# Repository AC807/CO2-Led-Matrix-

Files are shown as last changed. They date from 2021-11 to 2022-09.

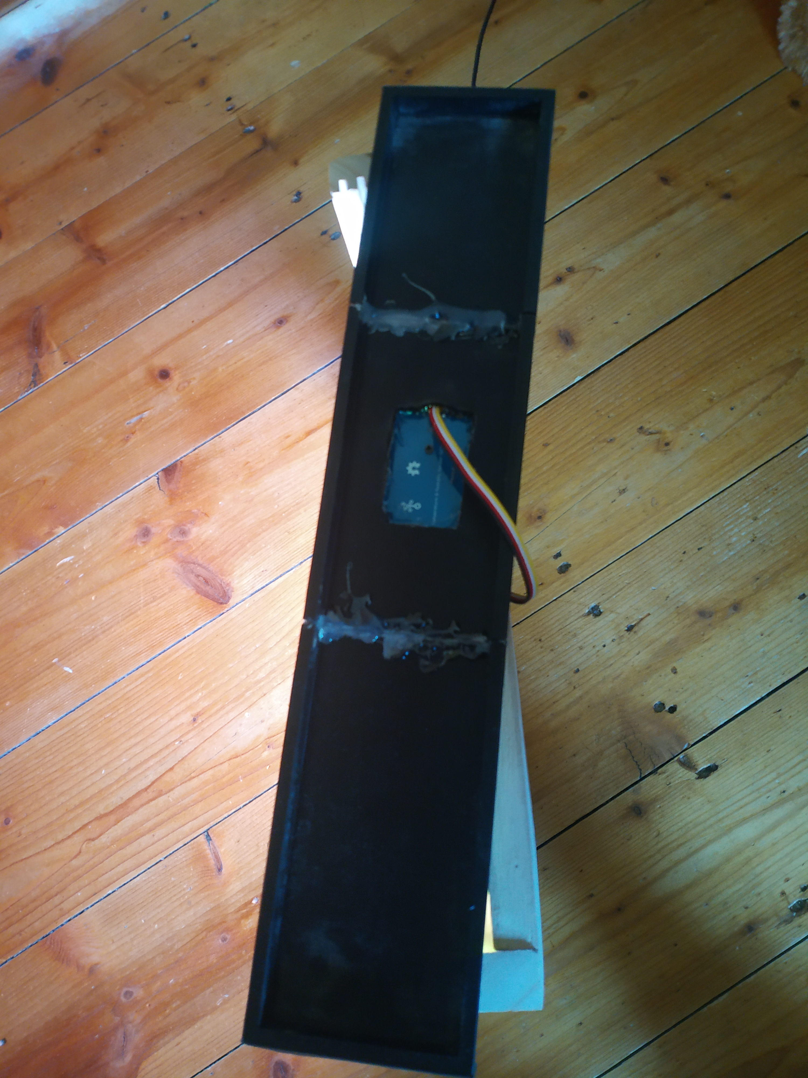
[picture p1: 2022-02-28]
Pres und bilder/IMG_20220207_152629.jpg

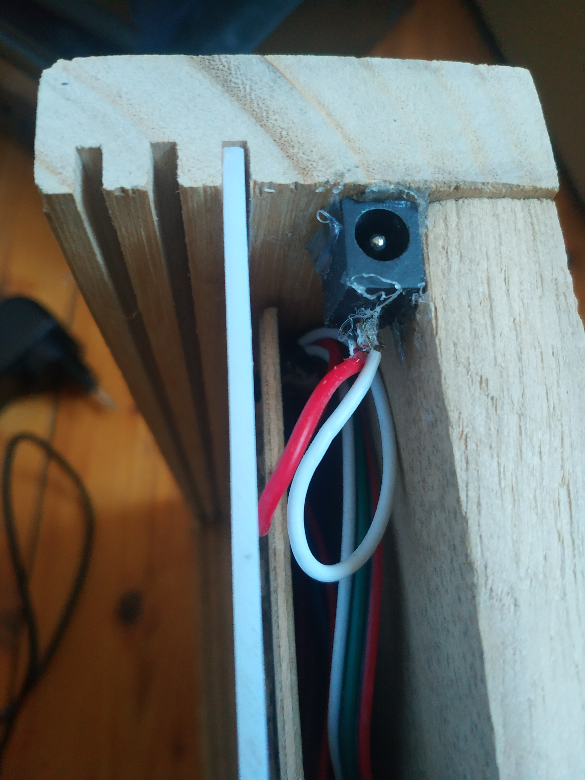
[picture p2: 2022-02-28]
Pres und bilder/IMG_20220207_162709.jpg

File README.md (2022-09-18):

# CO2-Led-Matrix-

Hallo,
das ist der Code zu meiner Jugend Forscht Arbeit mit dem Nahmen "Smarter CO2 Warner".
Hier die kurzfassung:

Ich habe mit einem Micro Computer (dem Octopus Board ESP-12F) und einem Co2 Sensor (dem SCD30) einen Co2 Warner für z.B. den Klassensaal gebaut. 
Der Co2 Wert wird auf einer 16x16 LED Matrix aus adressierbaren LED streifen angezeigt und zu einem Webserver geschickt. 
Unter 600ppm Co2 wird ein grüner Rahmen um die Zahl angezeigt, zwischen 600 und 1000pmm Co2 ein gelber Rahmen und über 1000ppm Co2 erscheint eine rote Warnmeldung. 
Außerdem habe ich ein Trend-Pfeil programmiert der anzeigt, ob der Co2 Wert konstant, fallend oder steigend ist. 
Für eine leichtere Handhabung des Warners habe ich aus Holz ein Gehäuse gebaut in welches man in 3 verschiedenen Höhen eine Milchglasscheibe einsetzen kann. 
Diese Scheibe ist dazu da, das Licht zu zerstreuen wodurch die Zahlen besser ablesbar werden.

Ich habe hierfür keine LED-Matrix libary genutzt.

Wenn jemand interresse am Code hat schreib mir einfach oder probiere ihn aus. (WIFI daten ändern)

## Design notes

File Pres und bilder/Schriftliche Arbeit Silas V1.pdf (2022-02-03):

# Smarter CO Warner ₂

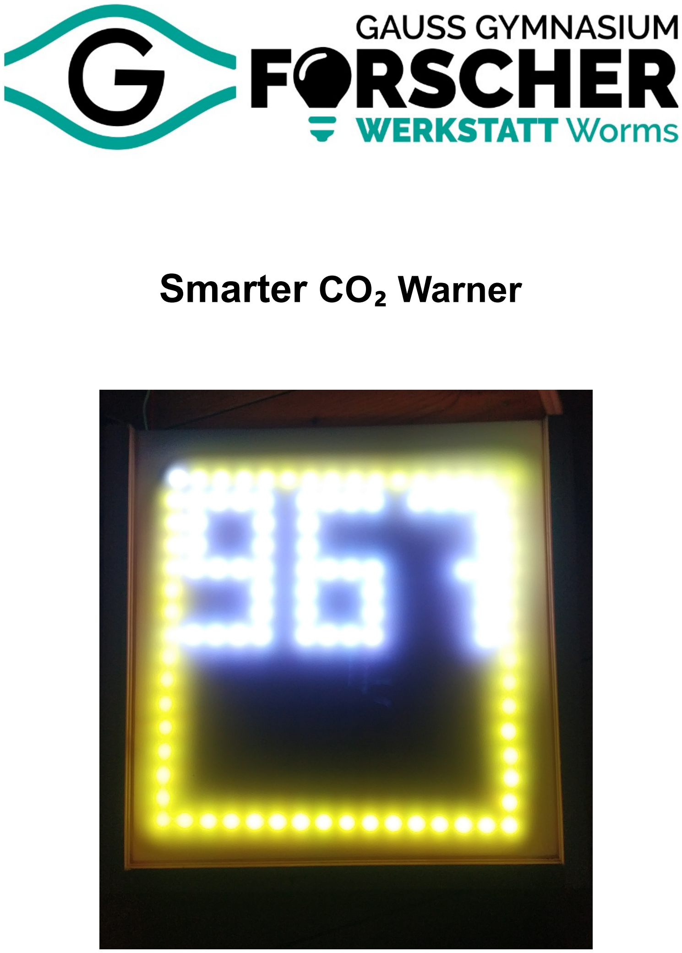
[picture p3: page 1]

## Diese Arbeit ist von Silas Wester 9D Gauß Gymnasium Worms

## Inhaltsverzeichnis

# Ziel

Mein Ziel ist es, einen praktischen CO Warner zu bauen der leicht abzulesen ist und ₂ nicht ablenkt. Hauptsächlich baue ich ihn für den Anwendungszweck in der Schule, da meine Schule noch keine CO Warner bekommen hat. ₂

## Warum ist ein CO Warner sinnvoll? ₂

Vom CO Gehalt in der Luft kann man Rückschlüsse auf die Raumluftqualität ₂ schließen da der CO Wert steigt, wenn sich mehrere Personen in einem Raum ₂ befinden und nicht gelüftet wird. Als Richtwert, wann man lüften sollte, habe ich 1000ppm gewählt, weil es z.B. vom Umweltbundesamt als Grenzwert angegeben wird.

## Ziel 1: Eine Basis die CO messen kann. ₂

Hier für habe ich ein Octopus Board und den SCD30 CO -, Temperatur- und ₂ Feuchtigkeitssensor verwendet. Ich habe eine Version des Sensors mit dem 12C BUS, weshalb ich nur 4 Leitungen brauche um den Sensor an mein Board anzuschließen.

Was ist ein Octopus Board?
Das Octopus Board basiert auf dem ESP-12F und ist ein Arduino-IDE kompatibles Entwicklerboard welches vom Umweltcampus der Hochschule Trier gebaut wird. Das Board ist interessant, da es z.B. einen WLAN Chip und einen 12C BUS Anschluss (für den CO Sensor) verbaut hat. ₂

Aufbau: Plug and code
Den CO Sensor musste ich nur an das Octopus Board anschließen und konnte ₂ direkt mit Programmieren beginnen.

Für den Code konnte ich große Teile des Beispiel Codes für den CO Sensor ₂ verwenden. Zum Visualisieren der Werte habe ich die auf dem Octopus board aufgelöteten NeoPixel LED verwendet. Bei einem CO Wehrt unter 600 ppm ₂ Leuchtet die LED grün, zwischen 600ppm und 1000ppm gelb und über 1000ppm rot. Außerdem gibt das Board den CO Wert auch über Serial.print an einen ₂ angeschlossenen PC aus.

## Ziel 2: Die CO Werte mit einem Webserver erreichbar ₂

machen.

Hierfür habe ich den Anbieter ThingSpeak benutzt, da er einfach zu benutzen ist und genau richtig für meinen Anwendungszweck. Auch hier habe ich wieder Teile des Beispiel Codes verwendet.
Jetzt misst der Sensor alle 2 sec. CO und das Octpus board schickt die Werte alle ₂ 10 sec. zu meinem ThingSpeak Server.
Bsp.:

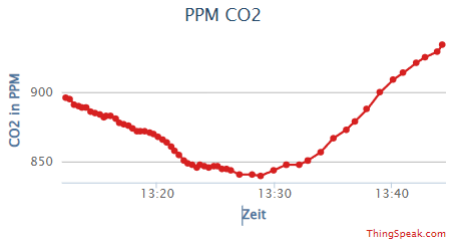
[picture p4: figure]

## Ziel 3: Eine intuitive Anzeige-Möglichkeit

Um den CO Wert anzuzeigen, habe ich eine LED Matrix mit 16x16 Pixeln aus ₂ WS28012b LEDs gebaut. Das hat den Vorteil, dass sie im Gegensatz zu einem normalen Display deutlich günstiger ist (insbesondere, wenn sie so groß ist, dass man sie in der Schule neben der Tafel hängend gut erkennen kann). Außerdem lenkt eine LED matrix auch nicht so ab wie ein Display.

Was ist eine LED Matrix?
Prinzipiell funktioniert eine LED Matrix ähnlich wie ein normales Display. In meinem Fall hat es aber nur eine Auflösung von 16x16 Pixeln. Ich habe hier 256 einzeln ansteuerbare LEDs verbaut, die ich dann so programmiert habe, dass man Zahlen anzeigen kann. Natürlich nur mit einer Auflösung von 16x16 Pixeln was aber für 3 Ziffern gut ausreicht.

Aufbau der Matrix:
Die Basis ist eine rechteckige Holzplatte auf die ich WS28012b LED-Streifen geklebt habe.
An die Stromkabel habe ich noch eine Buchse für ein 5V 4A Netzteil gelötet.
Nach 16 LEDs habe ich die Streifen abgeschnitten und in einer neuen Reihe angefangen.

Als nächstes musste ich die LED-Streifen mit Kabeln verbinden. Hierbei habe ich die Streifen so gelegt, dass die LEDs immer von links nach rechts angeordnet sind. Das hat den Vorteil, dass es leichter zu programmieren ist. Außerdem wird nur diese Anordnung von meinem gewählten Programm unterstützt.
Der Nachteil ist, dass ich die Kabel hinter der Matrix durchführen muss um wieder links am nächsten LED-Streifen anzukommen.
Damit ich die Matrix später in ein Gehäuse bauen kann und der Rand gleichmäßig ist, habe ich für die Kabel an jeder Seite der Reihen ein Loch gebohrt.

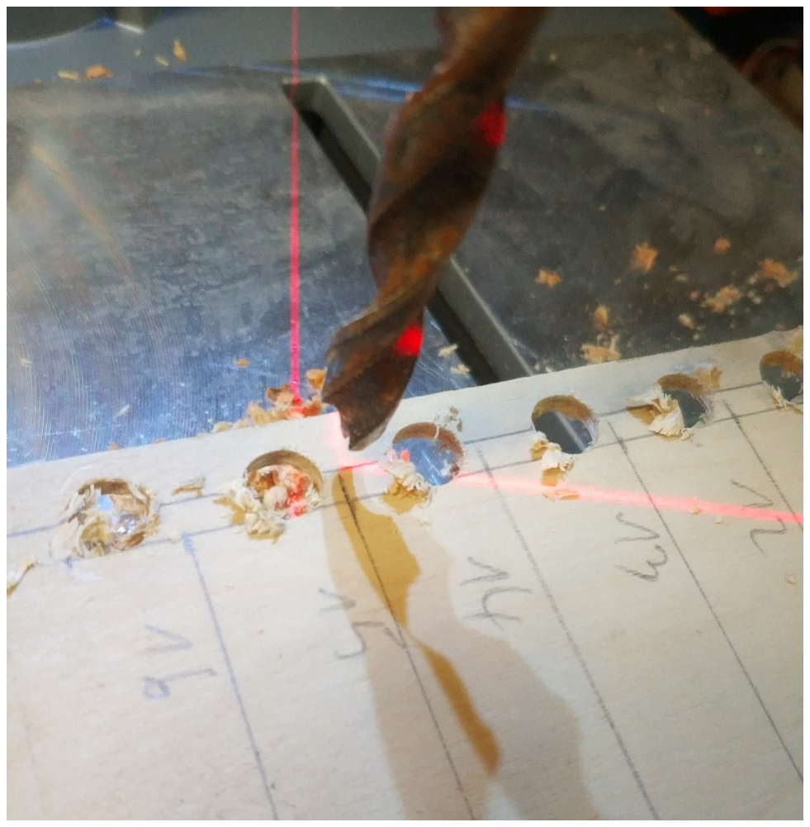
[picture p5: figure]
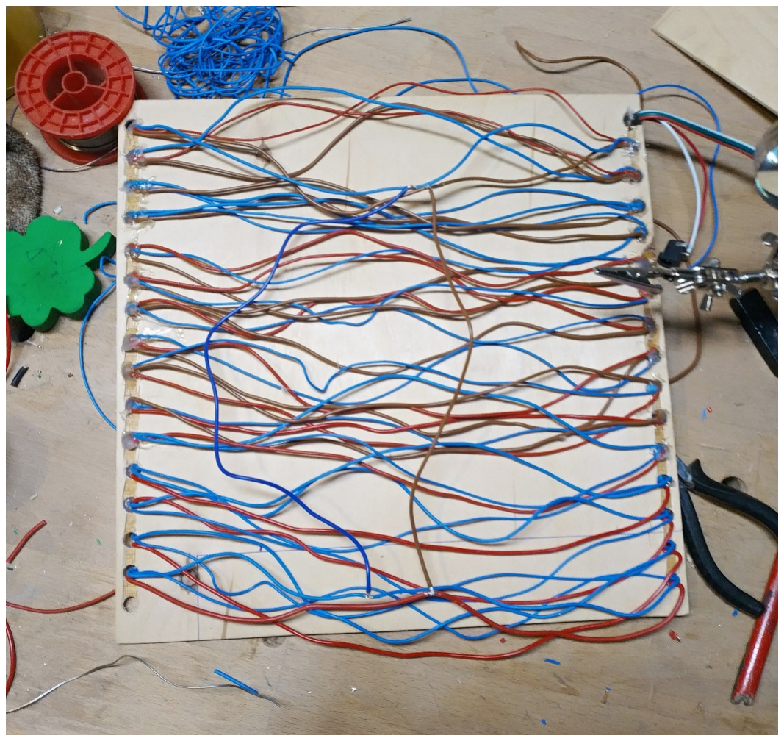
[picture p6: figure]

Beim Verlöten muss man aufpassen, dass man die Kabel vorher so biegt wie man sie braucht, da sie sich beim Löten mit Lötzinn vollsaugen und dann nicht mehr flexibel sind. Bei der 3. Reihe habe ich nämlich versucht die Kabel nach dem Löten noch einmal zu verbiegen und hab dabei das Lötpad von der Datenleitung abgerissen. Als Lösung habe ich dann das Kabel an die Unterseite des Streifens gelötet.
Beim ersten Test ist mir aufgefallen, dass wenn alle LEDs weiß leuchten sollen,die Farbe der letzten LEDs eher gelb ist. Dieser Effekt entsteht durch den Spannungsabfall. Das Problem habe ich behoben indem ich die letzten Stromleitungen mit den ersten verbunden habe.

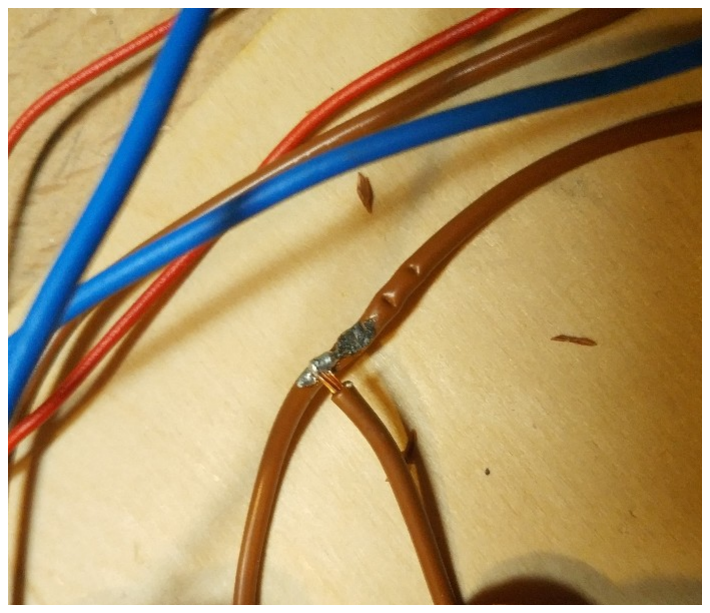
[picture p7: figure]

Was will ich auf der Matrix anzeigen?
- den CO Wert mit 3 Ziffern ₂
- einen Rahmen, der je nach CO Wert die Farbe wechselt (grün, gelb, rot) ₂
- eine große rote Meldung, wenn der CO Wert über 999ppm steigt ₂

Programmierung der LED-Matrix:
Um die LEDs einzeln anzusteuern, habe ich die FastLED library verwendet. Um 256 LEDs anzusteuern ist das aber sehr aufwendig, da ich für jede LED eine Zeile Code brauche um ihr zu sagen in welcher Farbe sie leuchten soll. Im Internet habe ich das Programm LEDMatrixControl von TylerTimoJ. In diesem Programm kann man auch unter anderem auf einer Fläche von 16x16 Pixeln zeichnen und sich die Bilder als Code für die FastLED library exportieren.
Dann habe ich die Zahlen von 0-9 für alle 3 Ziffern gezeichnet und exportiert.

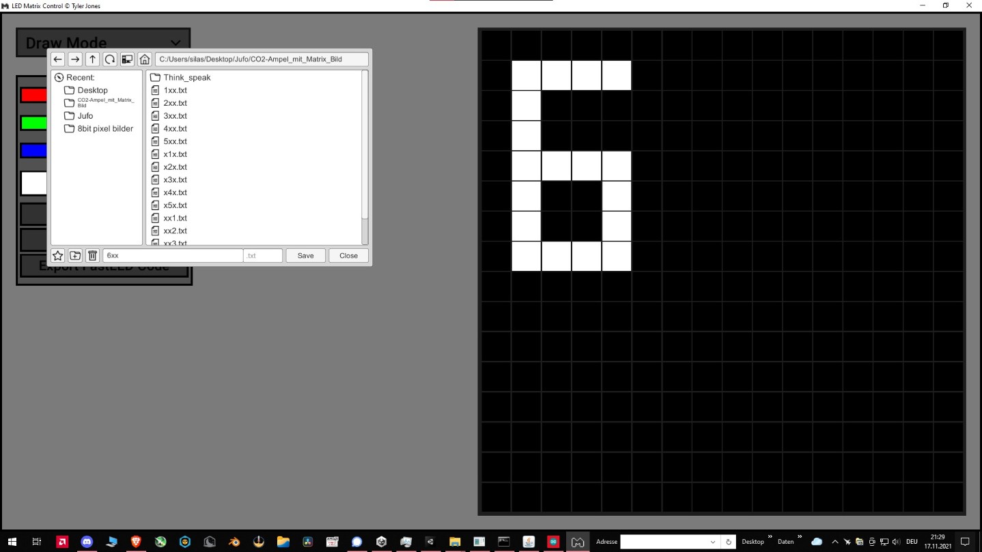
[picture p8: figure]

Als nächstes musste ich ein Programm entwickeln, welches den CO Wert bekommt ₂ und ausgibt welche LEDs wie leuchten müssen. Dafür muss es erst mal die Zahl in ihre Ziffern auftrennen da ich die Ziffern einzeln gezeichnet habe. Dafür habe ich mir zu Nutzen gemacht, dass bei einer Integer Variablen die Kommastellen wegfallen. Die Zahl wird durch 100 geteilt und ich erhalte die 100er Ziffer. Für die 10er Ziffer wird von der Zahl die 100er Ziffer mal 100 abgezogen und das ganze nochmal durch 10 geteilt. Für die 1er Ziffer wird auch die 100er Ziffer mal 100 abgezogen und dann das ganze durch die 10er Ziffer mal 10 subtrahiert.

Bsp.:
CO 378 ₂
100er Ziffer = 378/100 = 3
10er Ziffer = (378 - 3*100)/10 = 7
1er Ziffer = (378 – 3*100) – 7*10 = 8

Jetzt habe ich die Zahlen der einzelne Ziffern und kann z.B. sagen, dass wenn die 100er Ziffer 3 ist, führe den Code aus der auf der Matrix an der 100er stelle eine 3 anzeigt aus.

So sieht das in der Arduino IDE aus:

int CO = 0 ; //CO Wert ₂ | ₂
int w1xx = 0; //Zahl Ziffer 1
int wx1x = 0; //Zahl Ziffer 2
int wxx1 = 0; //Zahl Ziffer 3

void CO _Zerlegen (){ ₂
w1xx = CO /100; ₂
wx1x = (CO -w1xx*100)/10; ₂ wxx1 = (CO -w1xx*100)-wx1x*10; ₂ }

void loop() {
CO _Zerlegen (); ₂
if (w1xx == 1) v1xx();
if (w1xx == 2) v2xx();
if (w1xx == 3) v3xx();
if (w1xx == 4) v4xx();
...//abgekürzt ist zu lang
}

Als nächstes habe ich noch 3 Rahmen in grün, gelb und rot gezeichnet und integriert. Wenn der CO Wert unter 600ppm ist, wird der Code für den grünen Rahmen ₂ ausgeführt, zwischen 600ppm und 1000ppm der Code für den gelben Rahmen und über 1000ppm der Code für den roten Rahmen.

## Erster Testlauf

Im Dezember habe ich alle Komponenten miteinander verbunden und in meinem Zimmer platziert. Alles hat funktioniert wie geplant. Ich konnte den CO Wert sowohl ₂ auf der LED-Matrix als auch auf dem ThinkSpeak Webserver ablesen. Nach einiger Zeit ohne Lüftung wurde der Grenzwert erreicht und die Matrix leuchtete rot.

## Quellen

Warum ist ein CO Warner sinnvoll: ₂ | https://www.umweltbundesamt.de/richtig-lueften-
in-schulen#warum-ist-ein-regelmassiger-luftaustausch-in-klassenzimmerngrundsatzlich-wichtig-und-in-der-pandemie-umso-mehr (https://www.umweltbundesamt.de/richtig-lueften-in-schulen)
Octupus Board: https://www.bildung-forschung.digital/digitalezukunft/de/bildung/iot , https://www.umwelt-campus.de/iot-werkstatt/tutorials/schnellstart-octopusanschliessen-und-einrichten (https://www.umwelt-campus.de/iot-werkstatt/tutorials/schnellstart-octopus-anschliessen-und-einrichten)
CO Sensor: ₂ | https://www.distrelec.de/de/CO -temperatur-und-feuchtigkeitssensor- ₂
scd30-seeed-studio-101020634/p/30149396 (https://www.distrelec.de/de/co2-temperatur-und-feuchtigkeitssensor-scd30-seeed-studio-101020634/p/30149396)
Arduino IDE: https://www.arduino.cc/en/software
Fast LED : https://github.com/FastLED/FastLED
LEDMatrixControl: https://www.youtube.com/watch?v=YjzLWnPI_hg&t=1s

### Vielen Dank an Herr Kübler von der VSK-Technik Kübler für die

Unterstützung.

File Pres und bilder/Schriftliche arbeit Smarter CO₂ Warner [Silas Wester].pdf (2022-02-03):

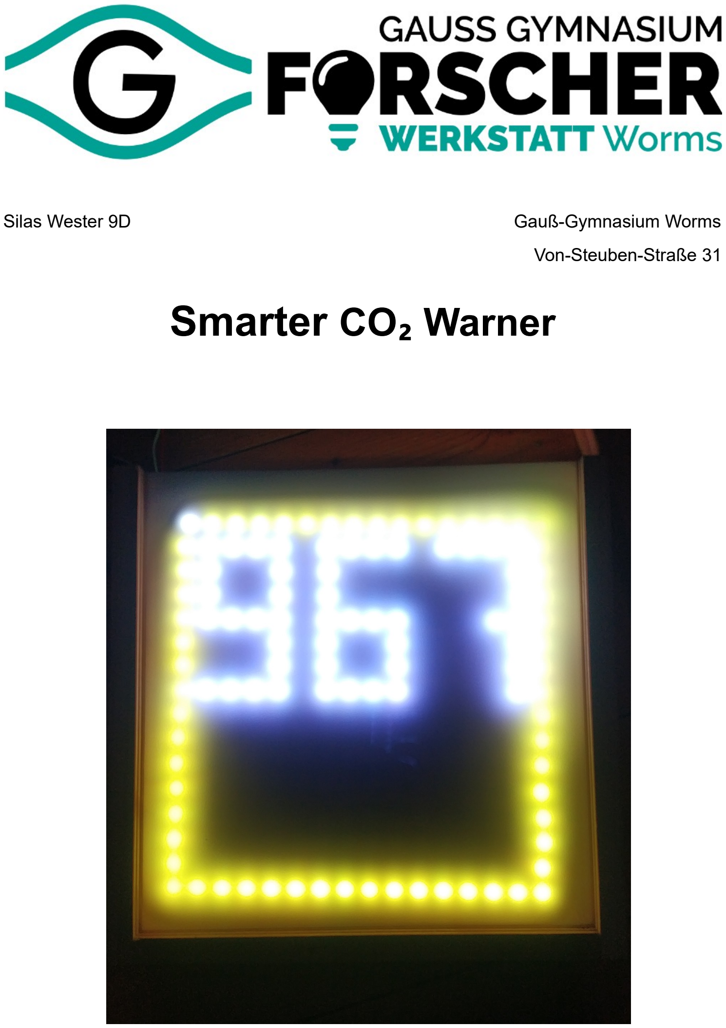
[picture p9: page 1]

Silas Wester 9D | Gauß-Gymnasium Worms
| Von-Steuben-Straße 31

# Smarter CO Warner ₂

## Inhaltsverzeichnis

# Ziel

Mein Ziel ist es, einen praktischen CO Warner zu bauen der leicht abzulesen ist und ₂ nicht ablenkt. Hauptsächlich baue ich ihn für den Anwendungszweck in der Schule, da meine Schule noch keine CO Warner bekommen hat und herkömmliche Modelle ₂ unpraktisch zum Ablesen sind oder keine genauen Werte liefern.

## Warum ist ein CO Warner sinnvoll? ₂

Vom CO Gehalt in der Luft kann man Rückschlüsse auf die Raumluftqualität ₂ schließen da der CO Wert steigt, wenn sich mehrere Personen in einem Raum ₂ befinden und nicht gelüftet wird. Als Richtwert, wann man lüften sollte, habe ich 1000 ppm gewählt, weil es z.B. vom Umweltbundesamt als Grenzwert angegeben wird.

## Ziel 1: Eine Basis die CO messen kann. ₂

Hier für habe ich ein Octopus Board und den SCD30 CO -, Temperatur- und ₂ Feuchtigkeitssensor verwendet. Ich habe eine Version des Sensors mit dem I²C BUS, weshalb ich nur 4 Leitungen brauche um den Sensor an mein Board anzuschließen.

Was ist ein Octopus Board?
Das Octopus Board basiert auf dem ESP-12F und ist ein Arduino-IDE kompatibles Entwicklerboard welches vom Umweltcampus der Hochschule Trier gebaut wird. Das Board ist interessant, da es z.B. einen WLAN Chip und einen I²C BUS Anschluss (für den CO Sensor) verbaut hat. ₂

Aufbau: Plug and code
Den CO Sensor musste ich nur an das ₂ Octopus Board anschließen und konnte direkt mit Programmieren beginnen.
Für den Code konnte ich große Teile des Beispiel Codes für den CO Sensor ₂

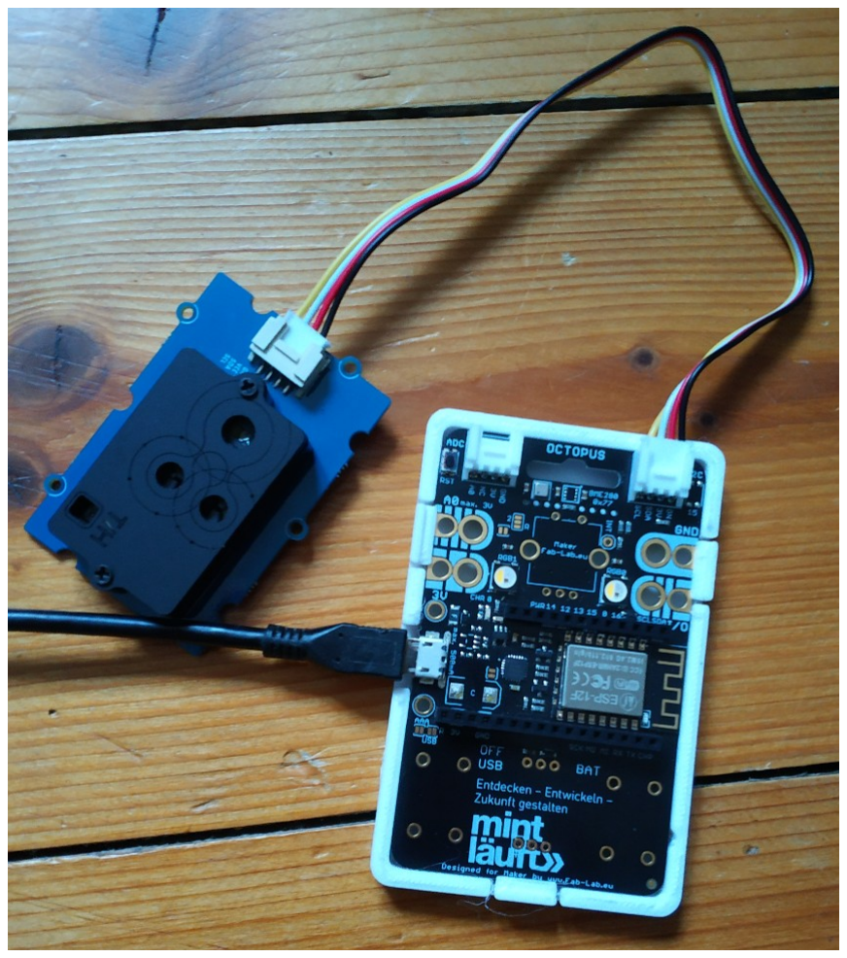
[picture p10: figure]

verwenden. Zum Visualisieren der Werte habe ich die auf dem Octopus board aufgelöteten NeoPixel LED verwendet. Bei einem CO₂ Wehrt unter 600 ppm Leuchtet die LED grün, zwischen 600 ppm und 1000 ppm gelb und über 1000 ppm rot.
Außerdem gibt das Board den CO Wert auch ₂ über Serial.print an einen angeschlossenen PC aus.

## Ziel 2: Die CO Werte mit einem Webserver erreichbar ₂

machen.

Hierfür habe ich den Anbieter ThingSpeak benutzt, da er einfach zu benutzen ist und genau richtig für meinen Anwendungszweck. Auch hier habe ich wieder Teile des Beispiel Codes verwendet.
Jetzt misst der Sensor alle 2 sec. CO und das Octpus board schickt die Werte alle ₂ 10 sec. zu meinem ThingSpeak Server.
Bsp.:

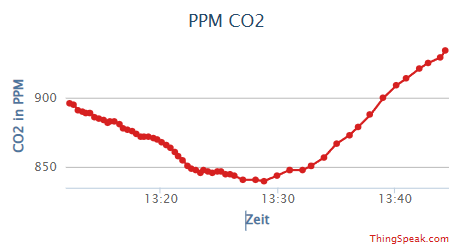
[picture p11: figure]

## Ziel 3: Eine intuitive Anzeige-Möglichkeit

Um den CO Wert anzuzeigen, habe ich eine LED Matrix mit 16x16 Pixeln aus ₂ WS28012b LEDs gebaut. Das hat den Vorteil, dass sie im Gegensatz zu einem normalen Display deutlich günstiger ist (insbesondere, wenn sie so groß ist, dass man sie in der Schule neben der Tafel hängend gut erkennen kann). Außerdem lenkt eine LED Matrix auch nicht so ab wie ein Display.

Was ist eine LED Matrix?
Prinzipiell funktioniert eine LED Matrix ähnlich wie ein normales Display. In meinem Fall hat es aber nur eine Auflösung von 16x16 Pixeln. Ich habe hier 256 einzeln ansteuerbare LEDs verbaut, die ich dann so programmiert habe, dass man Zahlen anzeigen kann. Natürlich nur mit einer Auflösung von 16x16 Pixeln was aber für 3 Ziffern gut ausreicht.

Aufbau der Matrix:
Die Basis ist eine rechteckige Holzplatte auf die ich WS28012b LED-Streifen geklebt habe.
An die Stromkabel habe ich noch eine Buchse für ein 5V 4A Netzteil gelötet.
Nach 16 LEDs habe ich die Streifen abgeschnitten und in einer neuen Reihe angefangen.

Als nächstes musste ich die LED-Streifen mit Kabeln verbinden. Hierbei habe ich die Streifen so gelegt, dass die LEDs immer von links nach rechts angeordnet sind. Das hat den Vorteil, dass es leichter zu programmieren ist. Außerdem wird nur diese Anordnung von meinem gewählten Programm unterstützt.
Der Nachteil ist, dass ich die Kabel hinter der Matrix durchführen muss um wieder links am nächsten LED-Streifen anzukommen.
Damit ich die Matrix später in ein Gehäuse bauen kann und der Rand gleichmäßig ist, habe ich für die Kabel an jeder Seite der Reihen ein Loch gebohrt.


Beim Verlöten muss man aufpassen, dass man die Kabel vorher so biegt wie man sie braucht, da sie sich beim Löten mit Lötzinn vollsaugen und dann nicht mehr flexibel sind. Bei der 3. Reihe habe ich nämlich versucht die Kabel nach dem Löten noch einmal zu verbiegen und hab dabei das Lötpad von der Datenleitung abgerissen. Als Lösung habe ich dann das Kabel an die Unterseite des Streifens gelötet.
Beim ersten Test ist mir aufgefallen, dass wenn alle LEDs weiß leuchten sollen,die Farbe der letzten LEDs eher gelb ist. Dieser Effekt entsteht durch den Spannungsabfall. Das Problem habe ich behoben indem ich die letzten Stromleitungen mit den ersten verbunden habe.


Was will ich auf der Matrix anzeigen?
- den CO Wert mit 3 Ziffern ₂
- einen Rahmen, der je nach CO Wert die Farbe wechselt (grün, gelb, rot) ₂
- eine große rote Meldung, wenn der CO Wert über 999 ppm steigt ₂

Programmierung der LED-Matrix:
Um die LEDs einzeln anzusteuern, habe ich die FastLED library verwendet. Um 256 LEDs anzusteuern ist das aber sehr aufwendig, da ich für jede LED eine Zeile Code brauche um ihr zu sagen in welcher Farbe sie leuchten soll. Im Internet habe ich das Programm LEDMatrixControl von TylerTimoJ. In diesem Programm kann man auch unter anderem auf einer Fläche von 16x16 Pixeln zeichnen und sich die Bilder als Code für die FastLED library exportieren.
Dann habe ich die Zahlen von 0-9 für alle 3 Ziffern gezeichnet und exportiert.


Als nächstes musste ich ein Programm entwickeln, welches den CO Wert bekommt ₂ und ausgibt welche LEDs wie leuchten müssen. Dafür muss es erst mal die Zahl in ihre Ziffern auftrennen da ich die Ziffern einzeln gezeichnet habe. Dafür habe ich mir zu Nutzen gemacht, dass bei einer Integer Variablen die Kommastellen wegfallen. Die Zahl wird durch 100 geteilt und ich erhalte die 100er Ziffer. Für die 10er Ziffer wird von der Zahl die 100er Ziffer mal 100 abgezogen und das ganze nochmal durch 10 geteilt. Für die 1er Ziffer wird auch die 100er Ziffer mal 100 abgezogen und dann das ganze durch die 10er Ziffer mal 10 subtrahiert.

Bsp.:
CO 378 ₂
100er Ziffer = 378/100 = 3
10er Ziffer = (378 - 3*100)/10 = 7
1er Ziffer = (378 – 3*100) – 7*10 = 8

Jetzt habe ich die Zahlen der einzelne Ziffern und kann z.B. sagen, dass wenn die 100er Ziffer 3 ist, führe den Code aus der auf der Matrix an der 100er stelle eine 3 anzeigt aus.

So sieht das in der Arduino IDE aus:

int CO = 0 ; //CO Wert ₂ | ₂
int w1xx = 0; //Zahl Ziffer 1
int wx1x = 0; //Zahl Ziffer 2
int wxx1 = 0; //Zahl Ziffer 3

void CO _Zerlegen (){ ₂
w1xx = CO /100; ₂
wx1x = (CO -w1xx*100)/10; ₂ wxx1 = (CO -w1xx*100)-wx1x*10; ₂ }

void loop() {
CO _Zerlegen (); ₂
if (w1xx == 1) v1xx();
if (w1xx == 2) v2xx();
if (w1xx == 3) v3xx();
if (w1xx == 4) v4xx();
...//abgekürzt ist zu lang
}

Als nächstes habe ich noch 3 Rahmen in grün, gelb und rot gezeichnet und integriert. Wenn der CO Wert unter 600 ppm ist, wird der Code für den grünen Rahmen ₂ ausgeführt, zwischen 600 ppm und 1000 ppm der Code für den gelben Rahmen und über 1000 ppm der Code für den roten Rahmen.

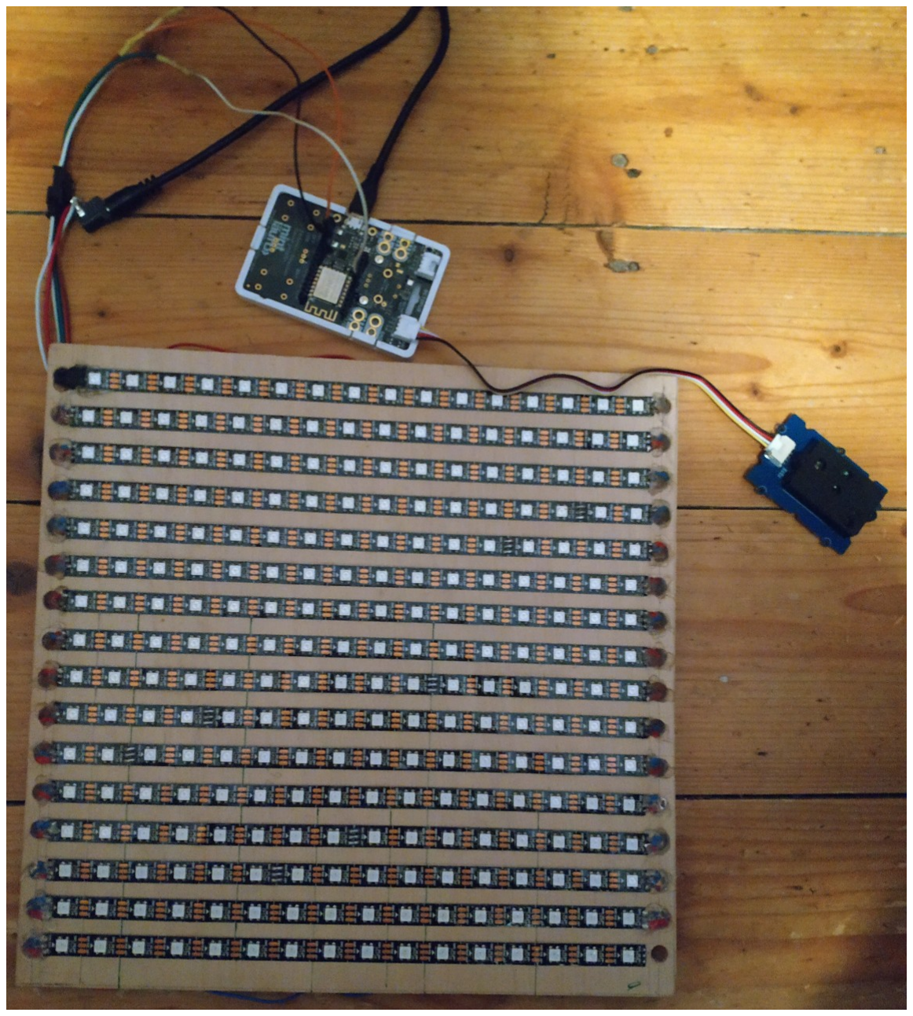
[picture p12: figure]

## Erster Testlauf und Ergebnis

Im Dezember habe ich alle Komponenten miteinander verbunden und in meinem Zimmer platziert. Alles hat funktioniert wie geplant. Ich konnte den CO Wert sowohl ₂ auf der LED-Matrix als auch auf dem ThinkSpeak Webserver ablesen. Nach einiger Zeit ohne Lüftung wurde der Grenzwert erreicht und die Matrix leuchtete rot. Dadurch wurden die Ziele erreicht. Das Gerät kann in der Schule eingesetzt werden um die Gesundheit der Schüler und Lehrer zu schützen. Außerdem kann durch die Verbesserung der Luftqualität die Konzentration und das Wohlbefinden gesteigert werden.

## Ausblick

Auf jeden Fall ist noch ein Gehäuse geplant, womit ich auch schon angefangen habe aber noch Teile 3d-drucken muss.
Einen eigenen Server als Alternative für ThinkSpeak wäre auch noch eine Überlegung.
Außerdem könnte man die CO Wert auch in die Schul-raumplanung einfließen ₂ lassen. Wenn eine Klasse z.B. kurzfristig in einen anderen Raum muss kann man den Raum danach auswählen wie viel CO in der Luft ist. ₂

## Quellen

Warum ist ein CO Warner sinnvoll: ₂ | https://www.umweltbundesamt.de/richtig-lueften-
in-schulen#warum-ist-ein-regelmassiger-luftaustausch-in-klassenzimmerngrundsatzlich-wichtig-und-in-der-pandemie-umso-mehr (https://www.umweltbundesamt.de/richtig-lueften-in-schulen)
Octupus Board: https://www.bildung-forschung.digital/digitalezukunft/de/bildung/iot , https://www.umwelt-campus.de/iot-werkstatt/tutorials/schnellstart-octopusanschliessen-und-einrichten (https://www.umwelt-campus.de/iot-werkstatt/tutorials/schnellstart-octopus-anschliessen-und-einrichten)
CO Sensor: ₂ | https://www.distrelec.de/de/CO -temperatur-und-feuchtigkeitssensor- ₂
scd30-seeed-studio-101020634/p/30149396 (https://www.distrelec.de/de/co2-temperatur-und-feuchtigkeitssensor-scd30-seeed-studio-101020634/p/30149396)
Arduino IDE: https://www.arduino.cc/en/software
Fast LED : https://github.com/FastLED/FastLED
LEDMatrixControl: https://www.youtube.com/watch?v=YjzLWnPI_hg&t=1s

### Vielen Dank an Herr Kübler von der VSK-Technik Kübler für die

Unterstützung.

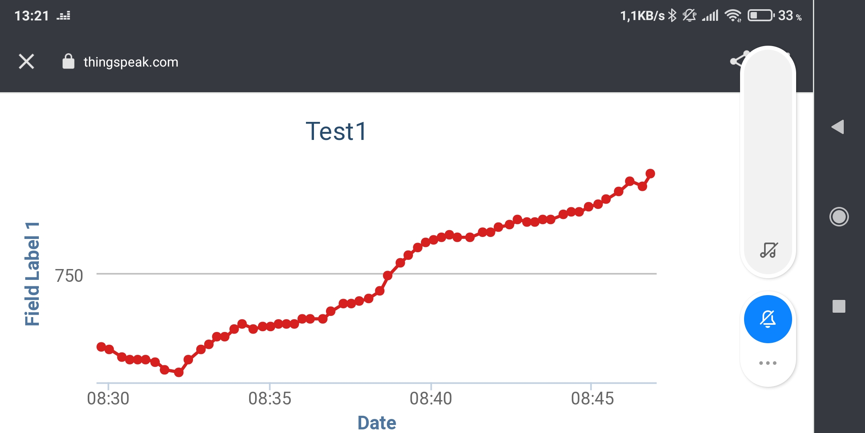
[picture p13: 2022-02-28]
Pres und bilder/Screenshot_2022-02-09-13-21-27-925_com.android.chrome.jpg

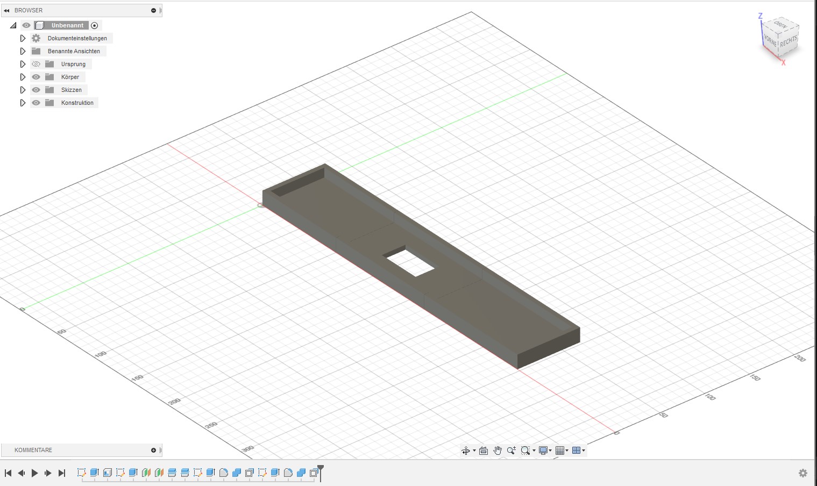
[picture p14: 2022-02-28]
Pres und bilder/Screenshot 2022-02-07 153404.jpg

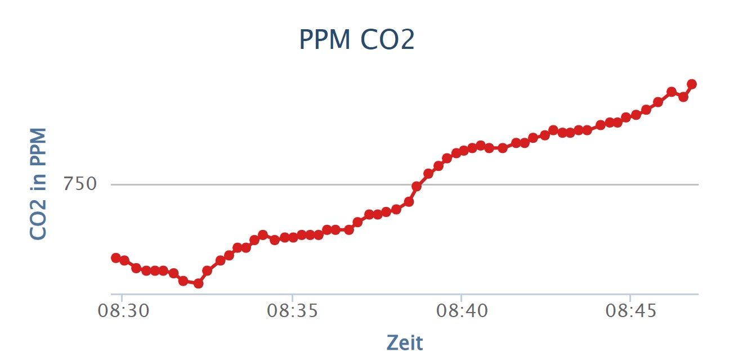
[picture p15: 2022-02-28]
Pres und bilder/Screenshot 2022-02-09 181810.jpg

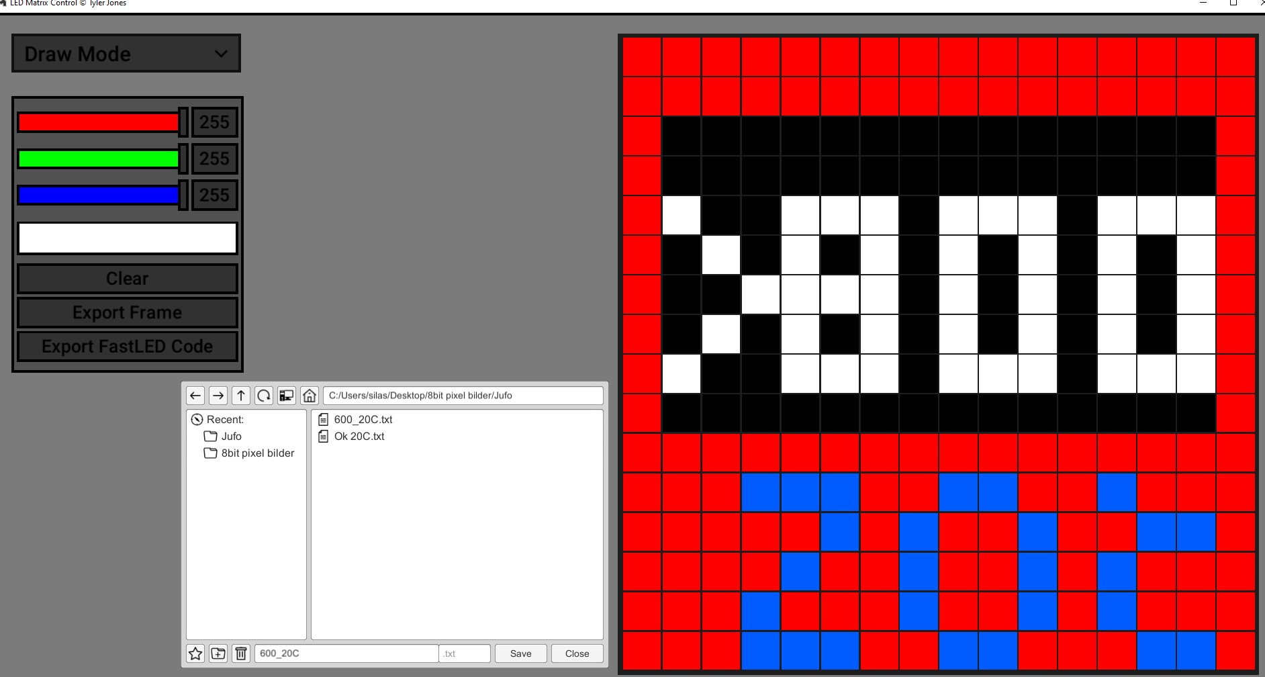
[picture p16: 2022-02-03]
Pres und bilder/Screenshot 2021-10-14 112025.jpg

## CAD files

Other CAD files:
JuFo_CO2_Matrix_Kappe_v1_v6.f3d

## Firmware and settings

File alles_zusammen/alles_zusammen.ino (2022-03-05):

#include "FastLED.h"
#define NUM_LEDS 256 //anzahl der LEDs (16x16)
#include <ESP8266WiFi.h>
#include <SparkFun_SCD30_Arduino_Library.h>
#include <Wire.h>
#include <Adafruit_NeoPixel.h>
CRGB leds[NUM_LEDS];
int CO2 = 0 ; //Co2-Wert
int alt_CO2 = 0; //alter Co2-Wert
int w1xx = 0;   //100er Stelle
int wx1x = 0;   //10er Stelle
int wxx1 = 0;   //1er Stelle
int CO2diff = -1; //CO2 Differenz (CO2-alt_CO2)

SCD30 airSensorSCD30; // Objekt SDC30 Umweltsensor
IPAddress myOwnIP; // ownIP for mDNS 

//--------------------------------------- HTTP-Get
int httpGET(String host, String cmd, String &antwort,int Port) {
  WiFiClient client; // Client über WiFi
  String text = "GET http://"+ host + cmd + " HTTP/1.1\r\n";
  text = text + "Host:" + host + "\r\n";
  text = text + "Connection:close\r\n\r\n";
  int ok = 1;
  if (ok) { // Netzwerkzugang vorhanden 
    ok = client.connect(host.c_str(),Port);// verbinde mit Client
    if (ok) {
      client.print(text);                 // sende an Client 
      for (int tout=1000;tout>0 && client.available()==0; tout--)
        delay(10);                         // und warte auf Antwort
      if (client.available() > 0)         // Anwort gesehen 
        while (client.available())         // und ausgewertet
          antwort = antwort + client.readStringUntil('\r');
      else ok = 0;
      client.stop(); 
      Serial.println(antwort);
    } 
  } 
  if (!ok) Serial.print(" no connection"); // Fehlermeldung
  return ok;
}

void setup(){ // Einmalige Initialisierung
  Wire.begin(); // ---- Initialisiere den I2C-Bus 
 
  Serial.begin(115200);  
  Serial.println();
  Wire.setClock(100000L);            // 100 kHz SCD30 
  Wire.setClockStretchLimit(200000L);// CO2-SCD30
  
  if (Wire.status() != I2C_OK) Serial.println("Fehler auf dem I2C-Bus");

  if (airSensorSCD30.begin() == false) {
    Serial.println("SCD30-Sensor Verbindung fehlerhaft, bitte prüfen"); 
  }

  airSensorSCD30.setAutoSelfCalibration(false); // Sensirion no auto calibration

  airSensorSCD30.setMeasurementInterval(2);     // CO2-Messung alle 2 s




  
  //------------ WLAN initialisieren 
  WiFi.persistent(false);
  WiFi.mode(WIFI_STA);
  delay(100);
  Serial.print ("\nWLAN connect to:");
  Serial.print("Gastzugang");
  WiFi.begin("Gastzugang","31155182573812659566");
  while (WiFi.status() != WL_CONNECTED) { // Warte bis Verbindung steht 
    delay(500); 
    Serial.print(".");    //Lade Punkte ausgeben
  };
  Serial.println ("\nconnected, meine IP:"+ WiFi.localIP().toString()); //IP addresse ausgeben
  myOwnIP = WiFi.localIP();
  
FastLED.addLeds<NEOPIXEL,13>(leds, NUM_LEDS); //LEDs hinzufügen
}

void loop() { // Kontinuierliche Wiederholung 
  CO2 = airSensorSCD30.getCO2() ;  //CO2 Wert in CO2 schriben
  Serial.print("CO2:"+String(String(CO2))); //CO2 ausgeben
  Serial.println();     //lehrzeile 

  { //Block------------------------------ sende Daten an Thingspeak (mit http GET) 
    Serial.println("\nThingspeak update ");
    String cmd = "/update?api_key="+ String("X3EXNK3ZO6R3IVI2");
    String host = "api.thingspeak.com";
    String antwort= " ";
    cmd = cmd +String("&field1="+String(CO2))+ "\n\r";
    httpGET(host,cmd,antwort,80);// und absenden 
  } // Blockende
 
CO2_Zerlegen ();    //schleife um CO2 in Ziffern zu zerlegen
empty();      //alle LEDs aus
//Zahl anzeigen:
if (w1xx == 1) v1xx();
if (w1xx == 2) v2xx();
if (w1xx == 3) v3xx();
if (w1xx == 4) v4xx();
if (w1xx == 5) v5xx();
if (w1xx == 6) v6xx();
if (w1xx == 7) v7xx();
if (w1xx == 8) v8xx();
if (w1xx == 9) v9xx();
if (w1xx == 0) v0xx();

if (wx1x == 1) vx1x();
if (wx1x == 2) vx2x();
if (wx1x == 3) vx3x();
if (wx1x == 4) vx4x();
if (wx1x == 5) vx5x();
if (wx1x == 6) vx6x();
if (wx1x == 7) vx7x();
if (wx1x == 8) vx8x();
if (wx1x == 9) vx9x();
if (wx1x == 0) vx0x();

if (wxx1 == 1) vxx1();
if (wxx1 == 2) vxx2();
if (wxx1 == 3) vxx3();
if (wxx1 == 4) vxx4();
if (wxx1 == 5) vxx5();
if (wxx1 == 6) vxx6();
if (wxx1 == 7) vxx7();
if (wxx1 == 8) vxx8();
if (wxx1 == 9) vxx9();
if (wxx1 == 0) vxx0();

Pfeil(); //Schleife um Trend-Pfeil anzuzeigen
farbeermitteln();   //Schleife um Farbigen Rahmen anzuzeigen
FastLED.show();     //Daten zur Matrix schicken 
Serial.println("CO2 1xx:"+String(String(w1xx)));
Serial.println("CO2 x1x:"+String(String(wx1x)));
Serial.println("CO2 xx1:"+String(String(wxx1)));
Serial.println("CO2 -alt_CO2:"+String(String(CO2diff)));
Serial.println("alt_CO2 :"+String(String(alt_CO2)));
alt_CO2 = CO2;   // CO2 in alt_CO2 speichern 
delay( 2000 );    //2 sec Warten bis neuer durchlauf
Serial.println("neuer durchlauf");
}

void CO2_Zerlegen (){
w1xx = CO2/100;
wx1x = (CO2-w1xx*100)/10;
wxx1 = (CO2-w1xx*100)-wx1x*10;
}

void Pfeil() {
CO2diff = CO2 - alt_CO2;   //CO2 Differenz berechnen
  if (( ( CO2diff ) > ( 8 ) ))    //ist die CO2diff größer als 8?
  {
    pf_steigend();
    Serial.println("steigender CO2 Wert");
    }
   else
     if (( ( CO2diff ) > ( 3 ) && ( CO2diff )< ( 9 ) ))     //ist die CO2diff zwichen als 4 und 8?
  {
    pf_leicht_steigend();
    Serial.println("leicht steigender CO2 Wert");
    }
   else
     if (( ( CO2diff ) < ( 4 ) && ( CO2diff )> ( -4 ) ))     //ist die CO2diff zwichen als 3 und -3?   
  {
    pf_gleich();
    Serial.println("Konstanter CO2 Wert");
    }
  else
     if (( ( CO2diff ) < ( -3 ) && ( CO2diff )> ( -9 ) ))     //ist die CO2diff zwichen als -4 und -8?
  {
  pf_leicht_sinkend();
  Serial.println("leicht sinkender CO2 Wert");
  }
  else
  if (( ( CO2diff ) < ( -8 ) ))     //ist die CO2diff kleiner als -8?
  {
  pf_sinkend();
  Serial.println("sinkender CO2 Wert");
    }
  }

void farbeermitteln()
{
  if (( ( CO2 ) < ( 600 ) ))     //ist CO2 kleiner als 600?
  {
    Serial.print("green");
    Serial.println();
    vGruen_Rahmen ();

  }
  else    //wenn nicht
  {
    if (( ( CO2 ) < ( 1000 ) ))     //ist CO2 kleiner als 1000?
    {
      Serial.print("yellow");
      Serial.println();
      vGelb_Rahmen ();
    }
    else    //wenn nicht
    {
      Serial.print("red");
      Serial.println();
     to_high ();
    }
  }
}


                                //alle Schleifen um etwas anzuzeigen
void vxx1(){
leds[29] = CRGB(255, 255, 255);
leds[30] = CRGB(255, 255, 255);
leds[44] = CRGB(255, 255, 255);
leds[46] = CRGB(255, 255, 255);
leds[59] = CRGB(255, 255, 255);
leds[62] = CRGB(255, 255, 255);
leds[78] = CRGB(255, 255, 255);
leds[94] = CRGB(255, 255, 255);
leds[110] = CRGB(255, 255, 255);
leds[126] = CRGB(255, 255, 255);
  }
void vxx2(){
leds[28] = CRGB(255, 255, 255);
leds[29] = CRGB(255, 255, 255);
leds[43] = CRGB(255, 255, 255);
leds[46] = CRGB(255, 255, 255);
leds[59] = CRGB(255, 255, 255);
leds[62] = CRGB(255, 255, 255);
leds[78] = CRGB(255, 255, 255);
leds[93] = CRGB(255, 255, 255);
leds[94] = CRGB(255, 255, 255);
leds[108] = CRGB(255, 255, 255);
leds[123] = CRGB(255, 255, 255);
leds[124] = CRGB(255, 255, 255);
leds[125] = CRGB(255, 255, 255);
leds[126] = CRGB(255, 255, 255);

  }
void vxx3(){
leds[28] = CRGB(255, 255, 255);
leds[29] = CRGB(255, 255, 255);
leds[43] = CRGB(255, 255, 255);
leds[46] = CRGB(255, 255, 255);
leds[62] = CRGB(255, 255, 255);
leds[76] = CRGB(255, 255, 255);
leds[77] = CRGB(255, 255, 255);
leds[78] = CRGB(255, 255, 255);
leds[94] = CRGB(255, 255, 255);
leds[107] = CRGB(255, 255, 255);
leds[110] = CRGB(255, 255, 255);
leds[124] = CRGB(255, 255, 255);
leds[125] = CRGB(255, 255, 255);
  }
void vxx4(){
leds[27] = CRGB(255, 255, 255);
leds[43] = CRGB(255, 255, 255);
leds[59] = CRGB(255, 255, 255);
leds[61] = CRGB(255, 255, 255);
leds[75] = CRGB(255, 255, 255);
leds[76] = CRGB(255, 255, 255);
leds[77] = CRGB(255, 255, 255);
leds[78] = CRGB(255, 255, 255);
leds[93] = CRGB(255, 255, 255);
leds[109] = CRGB(255, 255, 255);
leds[125] = CRGB(255, 255, 255);
  }
void vxx5(){
leds[27] = CRGB(255, 255, 255);
leds[28] = CRGB(255, 255, 255);
leds[29] = CRGB(255, 255, 255);
leds[30] = CRGB(255, 255, 255);
leds[43] = CRGB(255, 255, 255);
leds[59] = CRGB(255, 255, 255);
leds[75] = CRGB(255, 255, 255);
leds[76] = CRGB(255, 255, 255);
leds[77] = CRGB(255, 255, 255);
leds[78] = CRGB(255, 255, 255);
leds[94] = CRGB(255, 255, 255);
leds[110] = CRGB(255, 255, 255);
leds[123] = CRGB(255, 255, 255);
leds[124] = CRGB(255, 255, 255);
leds[125] = CRGB(255, 255, 255);
leds[126] = CRGB(255, 255, 255);
  }
void vxx6(){
leds[27] = CRGB(255, 255, 255);
leds[28] = CRGB(255, 255, 255);
leds[29] = CRGB(255, 255, 255);
leds[30] = CRGB(255, 255, 255);
leds[43] = CRGB(255, 255, 255);
leds[59] = CRGB(255, 255, 255);
leds[75] = CRGB(255, 255, 255);
leds[76] = CRGB(255, 255, 255);
leds[77] = CRGB(255, 255, 255);
leds[78] = CRGB(255, 255, 255);
leds[91] = CRGB(255, 255, 255);
leds[94] = CRGB(255, 255, 255);
leds[107] = CRGB(255, 255, 255);
leds[110] = CRGB(255, 255, 255);
leds[123] = CRGB(255, 255, 255);
leds[124] = CRGB(255, 255, 255);
leds[125] = CRGB(255, 255, 255);
leds[126] = CRGB(255, 255, 255);
  }
void vxx7(){
leds[27] = CRGB(255, 255, 255);
leds[28] = CRGB(255, 255, 255);
leds[29] = CRGB(255, 255, 255);
leds[30] = CRGB(255, 255, 255);
leds[46] = CRGB(255, 255, 255);
leds[62] = CRGB(255, 255, 255);
leds[77] = CRGB(255, 255, 255);
leds[78] = CRGB(255, 255, 255);
leds[94] = CRGB(255, 255, 255);
leds[110] = CRGB(255, 255, 255);
leds[126] = CRGB(255, 255, 255);
}
void vxx8(){
leds[27] = CRGB(255, 255, 255);
leds[28] = CRGB(255, 255, 255);
leds[29] = CRGB(255, 255, 255);
leds[30] = CRGB(255, 255, 255);
leds[43] = CRGB(255, 255, 255);
leds[46] = CRGB(255, 255, 255);
leds[59] = CRGB(255, 255, 255);
leds[62] = CRGB(255, 255, 255);
leds[75] = CRGB(255, 255, 255);
leds[76] = CRGB(255, 255, 255);
leds[77] = CRGB(255, 255, 255);
leds[78] = CRGB(255, 255, 255);
leds[91] = CRGB(255, 255, 255);
leds[94] = CRGB(255, 255, 255);
leds[107] = CRGB(255, 255, 255);
leds[110] = CRGB(255, 255, 255);
leds[123] = CRGB(255, 255, 255);
leds[124] = CRGB(255, 255, 255);
leds[125] = CRGB(255, 255, 255);
leds[126] = CRGB(255, 255, 255); 
}
void vxx9(){
leds[27] = CRGB(255, 255, 255);
leds[28] = CRGB(255, 255, 255);
leds[29] = CRGB(255, 255, 255);
leds[30] = CRGB(255, 255, 255);
leds[43] = CRGB(255, 255, 255);
leds[46] = CRGB(255, 255, 255);
leds[59] = CRGB(255, 255, 255);
leds[62] = CRGB(255, 255, 255);
leds[75] = CRGB(255, 255, 255);
leds[76] = CRGB(255, 255, 255);
leds[77] = CRGB(255, 255, 255);
leds[78] = CRGB(255, 255, 255);
leds[94] = CRGB(255, 255, 255);
leds[110] = CRGB(255, 255, 255);
leds[123] = CRGB(255, 255, 255);
leds[124] = CRGB(255, 255, 255);
leds[125] = CRGB(255, 255, 255);
leds[126] = CRGB(255, 255, 255);    
}
void vxx0(){
leds[27] = CRGB(255, 255, 255);
leds[28] = CRGB(255, 255, 255);
leds[29] = CRGB(255, 255, 255);
leds[30] = CRGB(255, 255, 255);
leds[43] = CRGB(255, 255, 255);
leds[46] = CRGB(255, 255, 255);
leds[59] = CRGB(255, 255, 255);
leds[62] = CRGB(255, 255, 255);
leds[75] = CRGB(255, 255, 255);
leds[78] = CRGB(255, 255, 255);
leds[91] = CRGB(255, 255, 255);
leds[94] = CRGB(255, 255, 255);
leds[107] = CRGB(255, 255, 255);
leds[110] = CRGB(255, 255, 255);
leds[123] = CRGB(255, 255, 255);
leds[124] = CRGB(255, 255, 255);
leds[125] = CRGB(255, 255, 255);
leds[126] = CRGB(255, 255, 255);  
}

  void vx1x(){
leds[24] = CRGB(255, 255, 255);
leds[25] = CRGB(255, 255, 255);
leds[39] = CRGB(255, 255, 255);
leds[41] = CRGB(255, 255, 255);
leds[54] = CRGB(255, 255, 255);
leds[57] = CRGB(255, 255, 255);
leds[73] = CRGB(255, 255, 255);
leds[89] = CRGB(255, 255, 255);
leds[105] = CRGB(255, 255, 255);
leds[121] = CRGB(255, 255, 255);
    
    }

void vx2x(){
leds[23] = CRGB(255, 255, 255);
leds[24] = CRGB(255, 255, 255);
leds[38] = CRGB(255, 255, 255);
leds[41] = CRGB(255, 255, 255);
leds[54] = CRGB(255, 255, 255);
leds[57] = CRGB(255, 255, 255);
leds[73] = CRGB(255, 255, 255);
leds[88] = CRGB(255, 255, 255);
leds[89] = CRGB(255, 255, 255);
leds[103] = CRGB(255, 255, 255);
leds[118] = CRGB(255, 255, 255);
leds[119] = CRGB(255, 255, 255);
leds[120] = CRGB(255, 255, 255);
leds[121] = CRGB(255, 255, 255);
      }
void vx3x(){
leds[23] = CRGB(255, 255, 255);
leds[24] = CRGB(255, 255, 255);
leds[38] = CRGB(255, 255, 255);
leds[41] = CRGB(255, 255, 255);
leds[57] = CRGB(255, 255, 255);
leds[71] = CRGB(255, 255, 255);
leds[72] = CRGB(255, 255, 255);
leds[73] = CRGB(255, 255, 255);
leds[89] = CRGB(255, 255, 255);
leds[102] = CRGB(255, 255, 255);
leds[105] = CRGB(255, 255, 255);
leds[119] = CRGB(255, 255, 255);
leds[120] = CRGB(255, 255, 255);
  }
void vx4x(){
leds[22] = CRGB(255, 255, 255);
leds[38] = CRGB(255, 255, 255);
leds[54] = CRGB(255, 255, 255);
leds[56] = CRGB(255, 255, 255);
leds[70] = CRGB(255, 255, 255);
leds[71] = CRGB(255, 255, 255);
leds[72] = CRGB(255, 255, 255);
leds[73] = CRGB(255, 255, 255);
leds[88] = CRGB(255, 255, 255);
leds[104] = CRGB(255, 255, 255);
leds[120] = CRGB(255, 255, 255);
  }
void vx5x(){
leds[22] = CRGB(255, 255, 255);
leds[23] = CRGB(255, 255, 255);
leds[24] = CRGB(255, 255, 255);
leds[25] = CRGB(255, 255, 255);
leds[38] = CRGB(255, 255, 255);
leds[54] = CRGB(255, 255, 255);
leds[70] = CRGB(255, 255, 255);
leds[71] = CRGB(255, 255, 255);
leds[72] = CRGB(255, 255, 255);
leds[73] = CRGB(255, 255, 255);
leds[89] = CRGB(255, 255, 255);
leds[105] = CRGB(255, 255, 255);
leds[118] = CRGB(255, 255, 255);
leds[119] = CRGB(255, 255, 255);
leds[120] = CRGB(255, 255, 255);
leds[121] = CRGB(255, 255, 255);
  }
void vx6x(){
leds[22] = CRGB(255, 255, 255);
leds[23] = CRGB(255, 255, 255);
leds[24] = CRGB(255, 255, 255);
leds[25] = CRGB(255, 255, 255);
leds[38] = CRGB(255, 255, 255);
leds[54] = CRGB(255, 255, 255);
leds[70] = CRGB(255, 255, 255);
leds[71] = CRGB(255, 255, 255);
leds[72] = CRGB(255, 255, 255);
leds[73] = CRGB(255, 255, 255);
leds[86] = CRGB(255, 255, 255);
leds[89] = CRGB(255, 255, 255);
leds[102] = CRGB(255, 255, 255);
leds[105] = CRGB(255, 255, 255);
leds[118] = CRGB(255, 255, 255);
leds[119] = CRGB(255, 255, 255);
leds[120] = CRGB(255, 255, 255);
leds[121] = CRGB(255, 255, 255);

  }
void vx7x(){
leds[22] = CRGB(255, 255, 255);
leds[23] = CRGB(255, 255, 255);
leds[24] = CRGB(255, 255, 255);
leds[25] = CRGB(255, 255, 255);
leds[41] = CRGB(255, 255, 255);
leds[57] = CRGB(255, 255, 255);
leds[72] = CRGB(255, 255, 255);
leds[73] = CRGB(255, 255, 255);
leds[89] = CRGB(255, 255, 255);
leds[105] = CRGB(255, 255, 255);
leds[121] = CRGB(255, 255, 255);

}
void vx8x(){
leds[22] = CRGB(255, 255, 255);
leds[23] = CRGB(255, 255, 255);
leds[24] = CRGB(255, 255, 255);
leds[25] = CRGB(255, 255, 255);
leds[38] = CRGB(255, 255, 255);
leds[41] = CRGB(255, 255, 255);
leds[54] = CRGB(255, 255, 255);
leds[57] = CRGB(255, 255, 255);
leds[70] = CRGB(255, 255, 255);
leds[71] = CRGB(255, 255, 255);
leds[72] = CRGB(255, 255, 255);
leds[73] = CRGB(255, 255, 255);
leds[86] = CRGB(255, 255, 255);
leds[89] = CRGB(255, 255, 255);
leds[102] = CRGB(255, 255, 255);
leds[105] = CRGB(255, 255, 255);
leds[118] = CRGB(255, 255, 255);
leds[119] = CRGB(255, 255, 255);
leds[120] = CRGB(255, 255, 255);
leds[121] = CRGB(255, 255, 255);

}
void vx9x(){
leds[22] = CRGB(255, 255, 255);
leds[23] = CRGB(255, 255, 255);
leds[24] = CRGB(255, 255, 255);
leds[25] = CRGB(255, 255, 255);
leds[38] = CRGB(255, 255, 255);
leds[41] = CRGB(255, 255, 255);
leds[54] = CRGB(255, 255, 255);
leds[57] = CRGB(255, 255, 255);
leds[70] = CRGB(255, 255, 255);
leds[71] = CRGB(255, 255, 255);
leds[72] = CRGB(255, 255, 255);
leds[73] = CRGB(255, 255, 255);
leds[89] = CRGB(255, 255, 255);
leds[105] = CRGB(255, 255, 255);
leds[118] = CRGB(255, 255, 255);
leds[119] = CRGB(255, 255, 255);
leds[120] = CRGB(255, 255, 255);
leds[121] = CRGB(255, 255, 255);
}
void vx0x(){
leds[22] = CRGB(255, 255, 255);
leds[23] = CRGB(255, 255, 255);
leds[24] = CRGB(255, 255, 255);
leds[25] = CRGB(255, 255, 255);
leds[38] = CRGB(255, 255, 255);
leds[41] = CRGB(255, 255, 255);
leds[54] = CRGB(255, 255, 255);
leds[57] = CRGB(255, 255, 255);
leds[70] = CRGB(255, 255, 255);
leds[73] = CRGB(255, 255, 255);
leds[86] = CRGB(255, 255, 255);
leds[89] = CRGB(255, 255, 255);
leds[102] = CRGB(255, 255, 255);
leds[105] = CRGB(255, 255, 255);
leds[118] = CRGB(255, 255, 255);
leds[119] = CRGB(255, 255, 255);
leds[120] = CRGB(255, 255, 255);
leds[121] = CRGB(255, 255, 255);
}


void v1xx(){  
leds[19] = CRGB(255, 255, 255);
leds[20] = CRGB(255, 255, 255);
leds[34] = CRGB(255, 255, 255);
leds[36] = CRGB(255, 255, 255);
leds[49] = CRGB(255, 255, 255);
leds[52] = CRGB(255, 255, 255);
leds[68] = CRGB(255, 255, 255);
leds[84] = CRGB(255, 255, 255);
leds[100] = CRGB(255, 255, 255);
leds[116] = CRGB(255, 255, 255);
}
void v2xx(){
leds[18] = CRGB(255, 255, 255);
leds[19] = CRGB(255, 255, 255);
leds[33] = CRGB(255, 255, 255);
leds[36] = CRGB(255, 255, 255);
leds[49] = CRGB(255, 255, 255);
leds[52] = CRGB(255, 255, 255);
leds[68] = CRGB(255, 255, 255);
leds[83] = CRGB(255, 255, 255);
leds[84] = CRGB(255, 255, 255);
leds[98] = CRGB(255, 255, 255);
leds[113] = CRGB(255, 255, 255);
leds[114] = CRGB(255, 255, 255);
leds[115] = CRGB(255, 255, 255);
leds[116] = CRGB(255, 255, 255);
}

void v3xx(){
leds[18] = CRGB(255, 255, 255);
leds[19] = CRGB(255, 255, 255);
leds[33] = CRGB(255, 255, 255);
leds[36] = CRGB(255, 255, 255);
leds[52] = CRGB(255, 255, 255);
leds[66] = CRGB(255, 255, 255);
leds[67] = CRGB(255, 255, 255);
leds[68] = CRGB(255, 255, 255);
leds[84] = CRGB(255, 255, 255);
leds[97] = CRGB(255, 255, 255);
leds[100] = CRGB(255, 255, 255);
leds[114] = CRGB(255, 255, 255);
leds[115] = CRGB(255, 255, 255);
  }
void v4xx(){
leds[17] = CRGB(255, 255, 255);
leds[33] = CRGB(255, 255, 255);
leds[49] = CRGB(255, 255, 255);
leds[51] = CRGB(255, 255, 255);
leds[65] = CRGB(255, 255, 255);
leds[66] = CRGB(255, 255, 255);
leds[67] = CRGB(255, 255, 255);
leds[68] = CRGB(255, 255, 255);
leds[83] = CRGB(255, 255, 255);
leds[99] = CRGB(255, 255, 255);
leds[115] = CRGB(255, 255, 255);
  }
void v5xx(){
leds[17] = CRGB(255, 255, 255);
leds[18] = CRGB(255, 255, 255);
leds[19] = CRGB(255, 255, 255);
leds[20] = CRGB(255, 255, 255);
leds[33] = CRGB(255, 255, 255);
leds[49] = CRGB(255, 255, 255);
leds[65] = CRGB(255, 255, 255);
leds[66] = CRGB(255, 255, 255);
leds[67] = CRGB(255, 255, 255);
leds[68] = CRGB(255, 255, 255);
leds[84] = CRGB(255, 255, 255);
leds[100] = CRGB(255, 255, 255);
leds[113] = CRGB(255, 255, 255);
leds[114] = CRGB(255, 255, 255);
leds[115] = CRGB(255, 255, 255);
leds[116] = CRGB(255, 255, 255);
  }    
void v6xx(){
leds[17] = CRGB(255, 255, 255);
leds[18] = CRGB(255, 255, 255);
leds[19] = CRGB(255, 255, 255);
leds[20] = CRGB(255, 255, 255);
leds[33] = CRGB(255, 255, 255);
leds[49] = CRGB(255, 255, 255);
leds[65] = CRGB(255, 255, 255);
leds[66] = CRGB(255, 255, 255);
leds[67] = CRGB(255, 255, 255);
leds[68] = CRGB(255, 255, 255);
leds[81] = CRGB(255, 255, 255);
leds[84] = CRGB(255, 255, 255);
leds[97] = CRGB(255, 255, 255);
leds[100] = CRGB(255, 255, 255);
leds[113] = CRGB(255, 255, 255);
leds[114] = CRGB(255, 255, 255);
leds[115] = CRGB(255, 255, 255);
leds[116] = CRGB(255, 255, 255);
  }      
void v7xx(){
leds[17] = CRGB(255, 255, 255);
leds[18] = CRGB(255, 255, 255);
leds[19] = CRGB(255, 255, 255);
leds[20] = CRGB(255, 255, 255);
leds[36] = CRGB(255, 255, 255);
leds[52] = CRGB(255, 255, 255);
leds[67] = CRGB(255, 255, 255);
leds[68] = CRGB(255, 255, 255);
leds[84] = CRGB(255, 255, 255);
leds[100] = CRGB(255, 255, 255);
leds[116] = CRGB(255, 255, 255);


}
void v8xx(){
leds[17] = CRGB(255, 255, 255);
leds[18] = CRGB(255, 255, 255);
leds[19] = CRGB(255, 255, 255);
leds[20] = CRGB(255, 255, 255);
leds[33] = CRGB(255, 255, 255);
leds[36] = CRGB(255, 255, 255);
leds[49] = CRGB(255, 255, 255);
leds[52] = CRGB(255, 255, 255);
leds[65] = CRGB(255, 255, 255);
leds[66] = CRGB(255, 255, 255);
leds[67] = CRGB(255, 255, 255);
leds[68] = CRGB(255, 255, 255);
leds[81] = CRGB(255, 255, 255);
leds[84] = CRGB(255, 255, 255);
leds[97] = CRGB(255, 255, 255);
leds[100] = CRGB(255, 255, 255);
leds[113] = CRGB(255, 255, 255);
leds[114] = CRGB(255, 255, 255);
leds[115] = CRGB(255, 255, 255);
leds[116] = CRGB(255, 255, 255);


}
void v9xx(){
leds[17] = CRGB(255, 255, 255);
leds[18] = CRGB(255, 255, 255);
leds[19] = CRGB(255, 255, 255);
leds[20] = CRGB(255, 255, 255);
leds[33] = CRGB(255, 255, 255);
leds[36] = CRGB(255, 255, 255);
leds[49] = CRGB(255, 255, 255);
leds[52] = CRGB(255, 255, 255);
leds[65] = CRGB(255, 255, 255);
leds[66] = CRGB(255, 255, 255);
leds[67] = CRGB(255, 255, 255);
leds[68] = CRGB(255, 255, 255);
leds[84] = CRGB(255, 255, 255);
leds[100] = CRGB(255, 255, 255);
leds[113] = CRGB(255, 255, 255);
leds[114] = CRGB(255, 255, 255);
leds[115] = CRGB(255, 255, 255);
leds[116] = CRGB(255, 255, 255);
}
void v0xx(){
leds[17] = CRGB(255, 255, 255);
leds[18] = CRGB(255, 255, 255);
leds[19] = CRGB(255, 255, 255);
leds[20] = CRGB(255, 255, 255);
leds[33] = CRGB(255, 255, 255);
leds[36] = CRGB(255, 255, 255);
leds[49] = CRGB(255, 255, 255);
leds[52] = CRGB(255, 255, 255);
leds[65] = CRGB(255, 255, 255);
leds[68] = CRGB(255, 255, 255);
leds[81] = CRGB(255, 255, 255);
leds[84] = CRGB(255, 255, 255);
leds[97] = CRGB(255, 255, 255);
leds[84] = CRGB(255, 255, 255);
leds[100] = CRGB(255, 255, 255);
leds[113] = CRGB(255, 255, 255);
leds[114] = CRGB(255, 255, 255);
leds[115] = CRGB(255, 255, 255);
leds[116] = CRGB(255, 255, 255);
}
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

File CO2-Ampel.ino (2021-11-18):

#include <SparkFun_SCD30_Arduino_Library.h>
#include <Wire.h>
#include <Adafruit_NeoPixel.h>

int CO2 = 0 ; //Co2-Wert

 
SCD30 airSensorSCD30; // Objekt SDC30 Umweltsensor
Adafruit_NeoPixel pixels = Adafruit_NeoPixel(2,13,NEO_GRBW + NEO_KHZ800);

void setup(){ // Einmalige Initialisierung
  Wire.begin(); // ---- Initialisiere den I2C-Bus 

  if (Wire.status() != I2C_OK) Serial.println("Fehler auf dem I2C-Bus");

  if (airSensorSCD30.begin() == false) {
    Serial.println("SCD30-Sensor Verbindung fehlerhaft, bitte prüfen"); 
  }

  airSensorSCD30.setAutoSelfCalibration(false); // Sensirion no auto calibration

  airSensorSCD30.setMeasurementInterval(2);     // CO2-Messung alle 2 s

  Serial.begin(115200);
  Serial.println();
  Wire.setClock(100000L);            // 100 kHz SCD30 
  Wire.setClockStretchLimit(200000L);// CO2-SCD30

  //Neopixel init
  pixels.begin();//-------------- Initialisierung Neopixel
  delay(1);
  pixels.show();
  pixels.setPixelColor(0,0,0,0,0); // alle aus
  pixels.setPixelColor(1,0,0,0,0);
  pixels.show();                 // und anzeigen
}

void loop() { // Kontinuierliche Wiederholung 
  CO2 = airSensorSCD30.getCO2() ;
  Serial.print("CO2:"+String(String(CO2)));
  Serial.println();
  farbeermitteln();  
  delay( 2000 );
}

void farbeermitteln()
{
  if (( ( CO2 ) < ( 600 ) ))
  {
    Serial.print("green");
    Serial.println();
    pixels.setPixelColor(0,0,255,0,0);
    pixels.show();
  }
  else
  {
    if (( ( CO2 ) < ( 1000 ) ))
    {
      Serial.print("yellow");
      Serial.println();
      pixels.setPixelColor(0,255,255,0,0);
      pixels.show();
    }
    else
    {
      Serial.print("red");
      Serial.println();
      pixels.setPixelColor(0,255,0,0,0);
    pixels.show();
    }
  }
}

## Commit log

2021-11-24 V2 Led_Matrix_Zalen_anzeigen Funktioniert
2021-12-09 V3 Thing_speak verbessert und alles zusammenfügen angefangen.
2021-12-09 V4 Schickt CO2 daten zu thingspeak
    -in alles_zusammen: CO2 Ampel und thingspeak zusammen
    Kann jetzt CO2 messen und zu thingspeak auf die Website schicken.
2021-12-09 V5 Led_Matrix_Zahlen_anzeigen funktioniert jetzt von 1xx-6xx; x1x-x5x; xx1-xx6
2021-12-09 V6 Led_Matrix_Zahlen_anzeigen funktioniert komplett alle Zahlen Hinzugefügt
    Led_Matrix_Zahlen_anzeigen:
    -Zahl(CO2) von 000-999 anzeigen
    -Zahl<600= Grüner Rahmen
    -600-1000= Gelber Rahmen
    Zahl>1000= To High Meldung
2021-12-09 V7 Der zusammengefaste Code funktioniert :+1:
    Es wird CO2 gemessen zu Thing speach geschickt und auf der Matrix angezeigt. Außerdem hab ich noch einen grünen Rahmen: unter 600ppm und einen gelben Rahmen: 600-999 ppm.
2022-02-28 More Pictures
    [JuFo_CO2_Matrix_Kappe_v1_v6.f3d]
